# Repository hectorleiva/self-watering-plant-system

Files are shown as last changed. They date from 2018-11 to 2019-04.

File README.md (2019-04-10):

# Self Watering Plant using Sparkfun Redboard + Johnny-Five

## Summary
Using the following pieces of equipment:
- [Moisture Sensor](https://www.sparkfun.com/products/13322)
- [Sonar Sensor](https://www.robotshop.com/en/sharp-gp2y0a02yk0f-ir-range-sensor.html)
- [4 Channel DC 5V Power Relay](https://www.amazon.com/JBtek-Channel-Module-Arduino-Raspberry/dp/B00KTEN3TM)
- [Sparkfun RedBoard](https://www.sparkfun.com/products/13975)
- [Submersible Water Pump](https://www.amazon.com/Small-Water-Pump-4-5v-Available/dp/B077X1NKRL)

I created a watering system that would allow a plant whose moisture falls below a certain threshold to be able to get water from a water source that has enough water to be able to water the plant.

Note: A 1-Channel DC 5V Power Relay is also acceptable

## How it works

### Check the Water Level
The container which holds the water has a Sonar Sensor that is checking the level of the water every second.

This is used to ensure that if the soil becomes too dry, that there is any water at all to pump out and deliver to the plant.

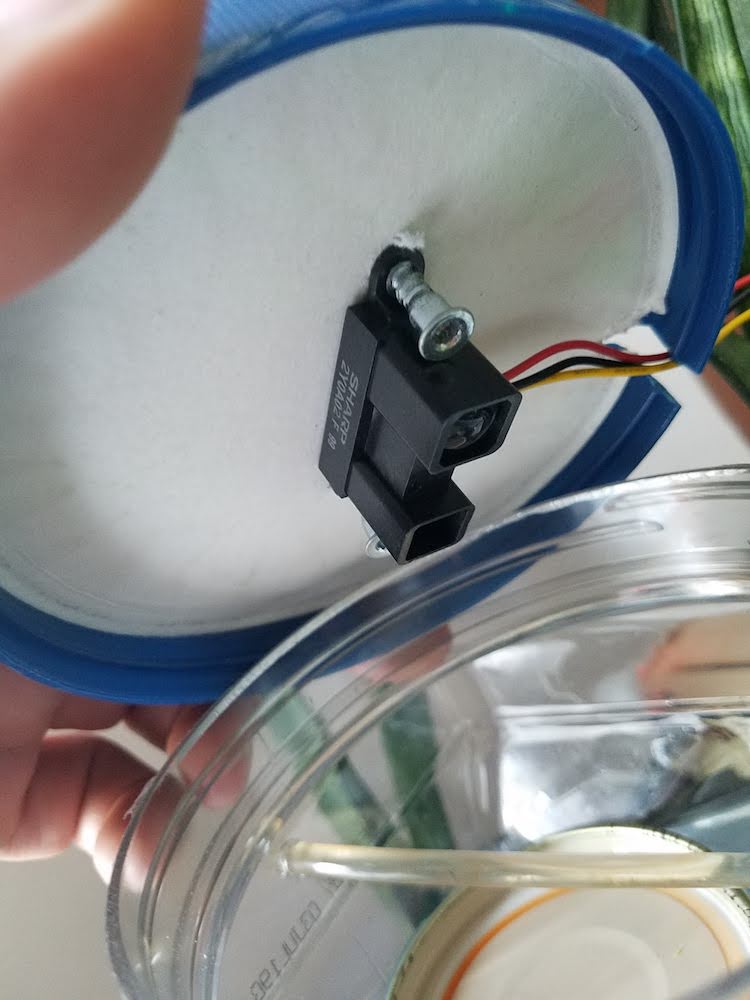
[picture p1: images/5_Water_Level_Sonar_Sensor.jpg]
WaterLevelSonarSensor


The surface of the water is _not_ capable of creating a hard enough surface to reflect back an accurate reading as to how much water is in the container. That is why I'm using a foam material that floats on the surface to bounce off of to get a more accurate reading.

### Check the Soil Moisture Level
The plant has a soil moisture sensor plugged into the soil to ensure that the plant has enough water and will send readings back to the microcontroller.

The microcontroller logic will check if the values being sent back fall in a certain threshold value and if it does, then it will water the plant.

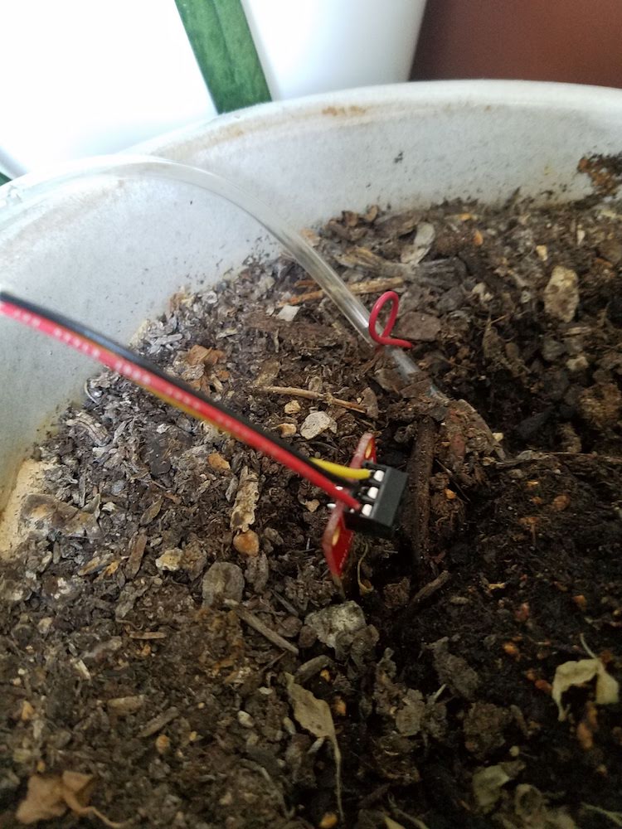
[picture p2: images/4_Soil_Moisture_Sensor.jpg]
SoilMoistureSensor


### If the plant is both dry and there's enough water...
The microcontroller at this point will send a signal to the 4-channel power relay which will activate the submersible water pump. The pump will continue running as long as:

a) There is enough water in the container

b) The plant is dry

If either of these conditions are `False`, then the pump will automatically turn off.

### Johnny-Five usage
I believe that this was a good exercise project to try out Johnny-Five as a framework to write for a microcontroller. To get started yourself with this project, you'll have to run the instructions located here:

https://github.com/rwaldron/johnny-five/wiki/Getting-Started

which includes instructions on how to flash your Arduino-comptabile microcontroller to be able to run this code on the microcontroller.

### Caveats
Before starting this project, I had falsely assumed that Johnny-Five was capable of running the Javascript code as if it was somehow read and transcribed into the Java code that was necessary for the Arduino.

What Johnny-Five does instead, is that there's a *host machine* that is running a Node.js process that will actively transcribe the code for the Arduino.

Meaning that there has to be a machine that is able to run Node.js that is running along side the Arduino. This machine does not need to be another computer altogether - but a Raspberry Pi works out for this particular solution.

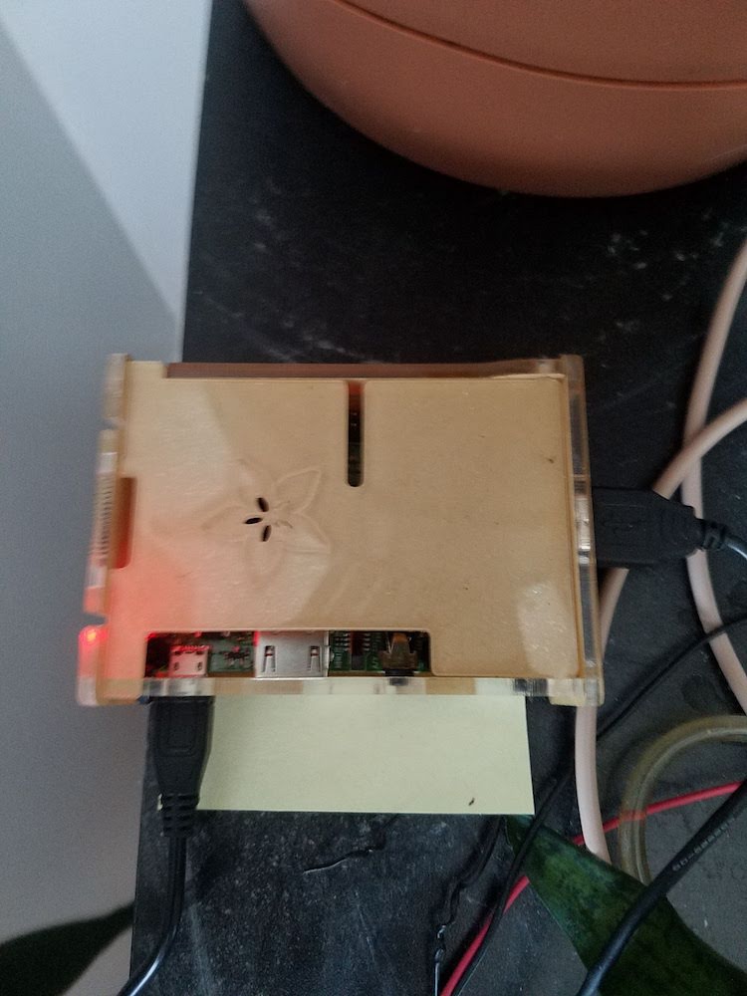
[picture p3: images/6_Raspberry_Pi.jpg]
RaspberryPi


## Gallery

### Final Set-up
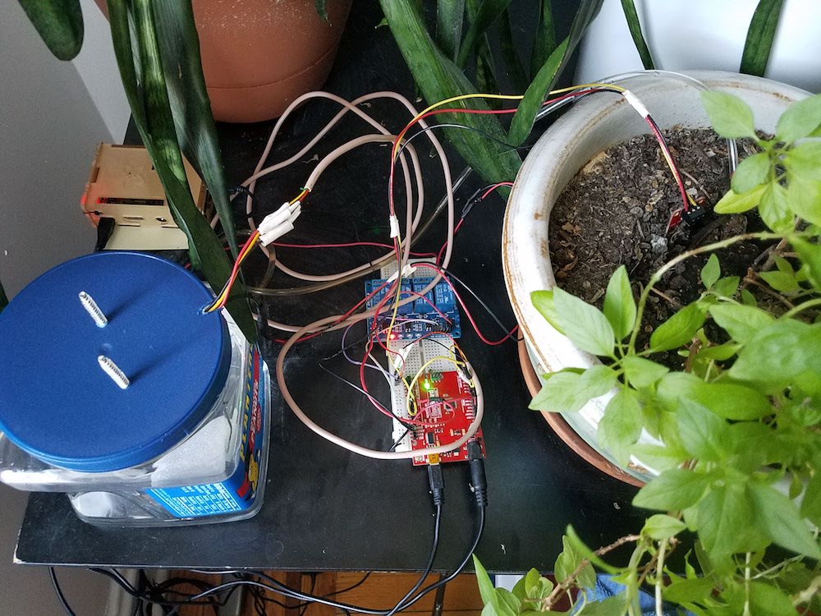
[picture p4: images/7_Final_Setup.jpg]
Setup


### Fritzing Diagram
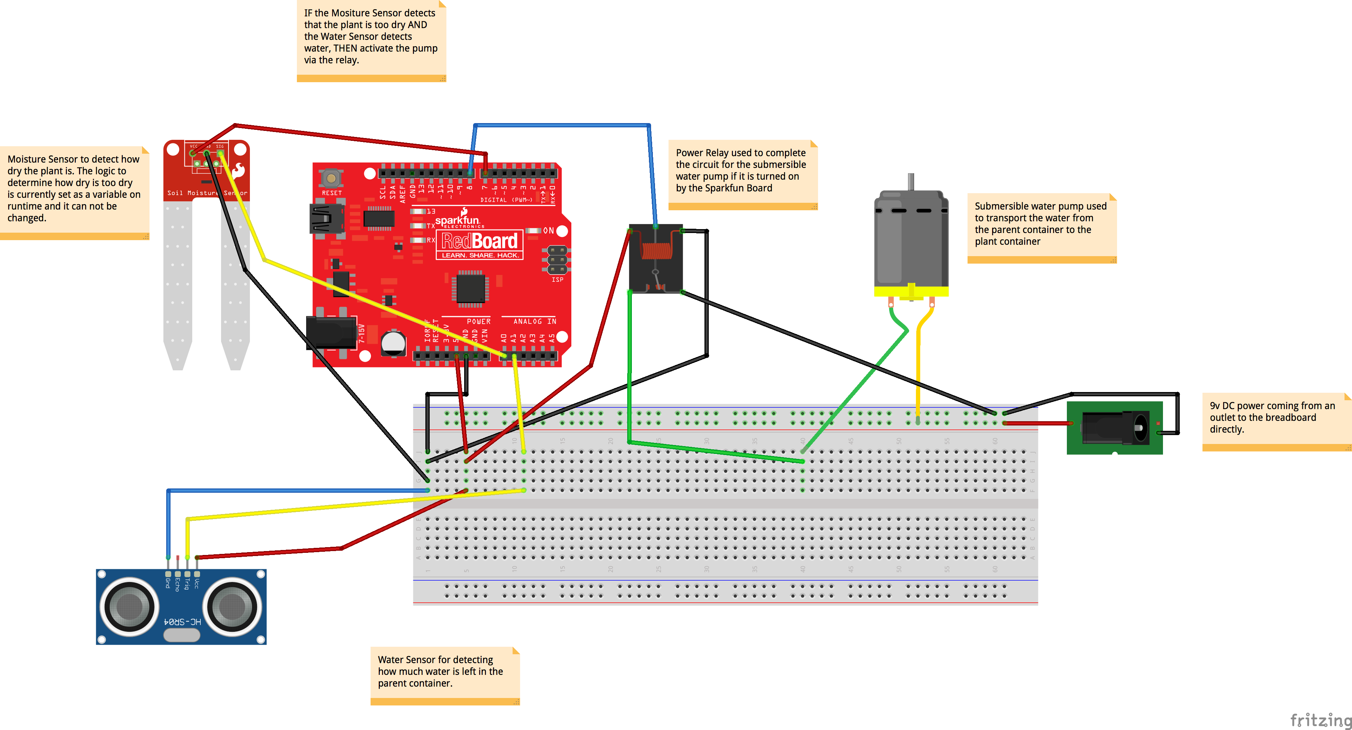
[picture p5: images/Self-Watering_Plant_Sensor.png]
ComponentSetup


### Some of the individual components
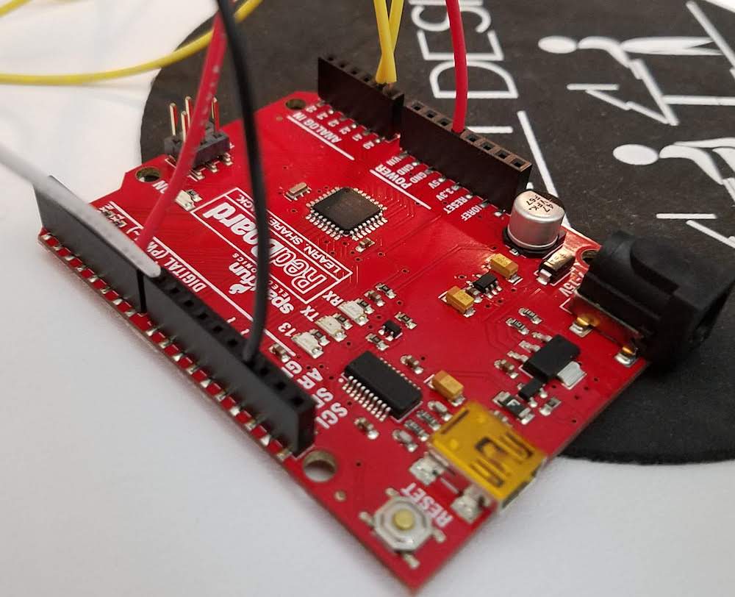
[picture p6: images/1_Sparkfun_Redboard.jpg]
RedBoard

BreadBoard
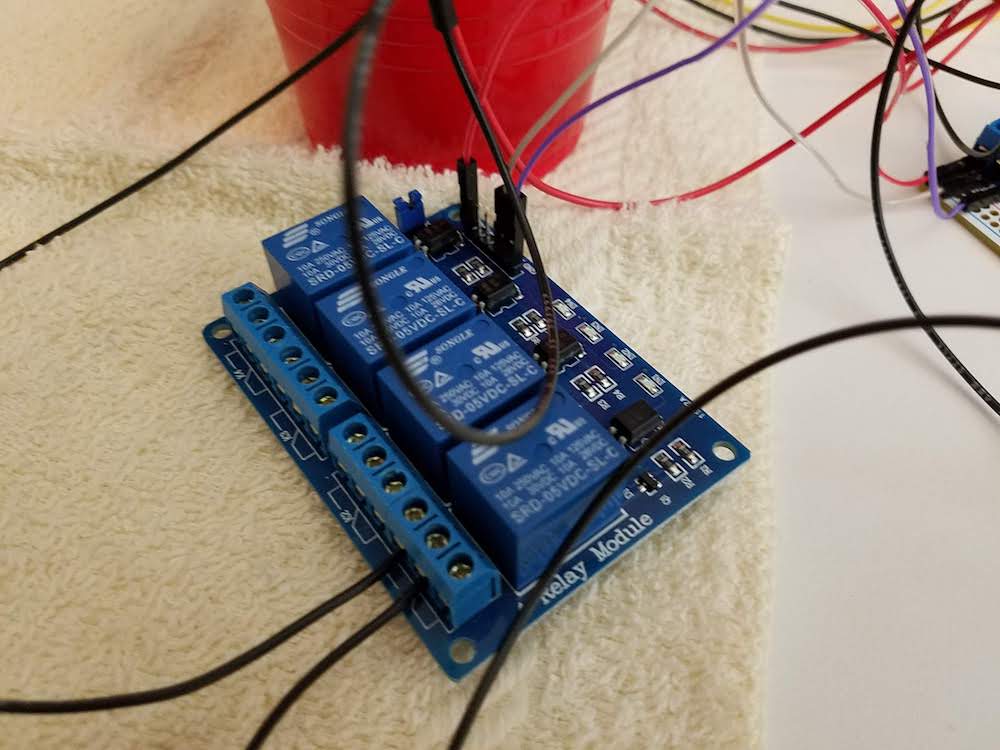
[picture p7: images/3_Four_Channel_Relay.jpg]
FourChannelRelay


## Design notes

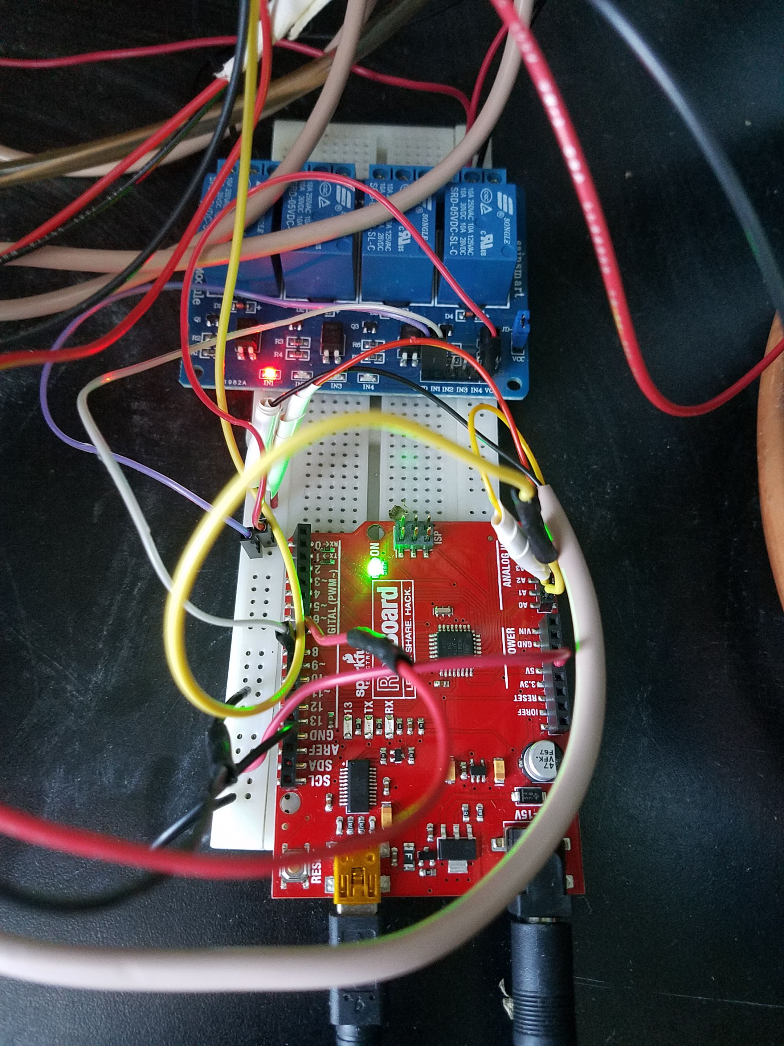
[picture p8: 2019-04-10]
images/2_Breadboard.jpg

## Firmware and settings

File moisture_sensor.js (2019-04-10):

var five = require('johnny-five');
var board = new five.Board();

// Sonar Sensor
var sonarSensorAnalogReadPin = 1; // Analog Pin 1

// Relay
var relayDigitalSwitchPin = 8; // Digital Pin 8
var RELAY_OFF = 0;
var RELAY_ON = 1;

// Relay Operations
function startWateringPlants(board) {
  board.digitalWrite(relayDigitalSwitchPin, RELAY_ON);
}

function stopWateringPlants(board) {
  board.digitalWrite(relayDigitalSwitchPin, RELAY_OFF);
}

// Checks
function waterLevelCheck(value, minWaterLevelVal) {
  if (value <= minWaterLevelVal) {
    return true;
  } else {
    return false;
  }
}

function isPlantDry(value, targetMoistureVal) {
  if (value <= targetMoistureVal) {
    return true;
  } else {
    return false;
  }
}

function togglePlantWatering(board, incomingSoilMoistureVal, waterLevelIsAcceptable, targetMoistureVal) {
  var moistureSensorBufferValue = 25; // Must be above this value to avoid accidently getting low-reading voltage values randomly

  if (incomingSoilMoistureVal > moistureSensorBufferValue) {
    if (waterLevelIsAcceptable) {
      if (isPlantDry(incomingSoilMoistureVal, targetMoistureVal)) {
        board.info("Board", "plant is dry!");
        startWateringPlants(board);
      } else {
        board.info("Board", "plant is doing a-ok");
        stopWateringPlants(board);
      }
    } else {
      stopWateringPlants(board);
    }
  }
}

function turnOnDigitalReaders(board, soilDigitalPowerPin) {
  board.digitalWrite(soilDigitalPowerPin, 1); // Turn on to start reading the soilDataPin
}

board.on('ready', function() {
  var waterLevelIsAcceptable = false;

  // Moisture Sensor
  var soilAnalogReadPin = 0; // Analog Pin 0
  var soilDigitalPowerPin = 7; // Digital Pin 7

  // Moisture Sensor Initial
  var targetMoistureVal = 500;

  // Water Sensor Values
  var minWaterLevelVal = 550;

  // This will limit sampling of all Analog Input
  // and I2C sensors to once per second (1000 milliseconds)
  this.samplingInterval(1000);

  board.pinMode(soilDigitalPowerPin, five.Pin.OUTPUT);
  board.pinMode(soilAnalogReadPin, five.Pin.INPUT);

  board.pinMode(relayDigitalSwitchPin, five.Pin.OUTPUT);

  // Ensure this is turned off when starting
  board.digitalWrite(soilDigitalPowerPin, 0);
  board.digitalWrite(relayDigitalSwitchPin, RELAY_OFF);

  turnOnDigitalReaders(board, soilDigitalPowerPin);

  board.analogRead(sonarSensorAnalogReadPin, function(val) {
    waterLevelIsAcceptable = waterLevelCheck(val, minWaterLevelVal);
  });

  board.analogRead(soilAnalogReadPin, function(voltage) {
    togglePlantWatering(board, voltage, waterLevelIsAcceptable, targetMoistureVal);
  });

  board.on("exit", function() {
    board.digitalWrite(relayDigitalSwitchPin, RELAY_OFF);
    board.digitalWrite(soilDigitalPowerPin, 0);
    board.info("Board", "Exiting");
  });
});

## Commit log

2018-11-19 adding a buffer voltage reading value
2019-01-25 adding update about the usage of a 1-channel power relay
2019-02-26 inverting due to stupid arduino third state
    [moisture_sensor.js]
2019-03-29 using a sonar sensor now
2019-04-10 cleaning up the code, adding sonar sensor documentation
    [Self-Watering Plant Sensor.fzz]
